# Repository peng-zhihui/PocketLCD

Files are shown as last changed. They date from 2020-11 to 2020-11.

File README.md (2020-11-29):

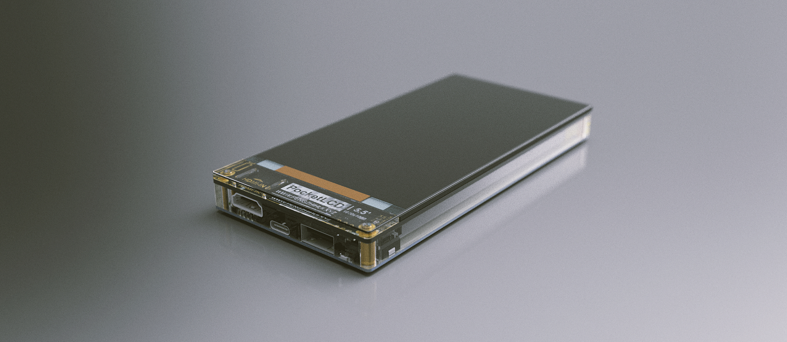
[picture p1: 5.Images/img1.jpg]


# PocketLCD: 带充电宝功能的便携显示器

项目的视频介绍可以在这里看： [【自制】你的下一个显示器，可能是个充电宝？？](https://www.bilibili.com/video/BV17D4y1X7AT)

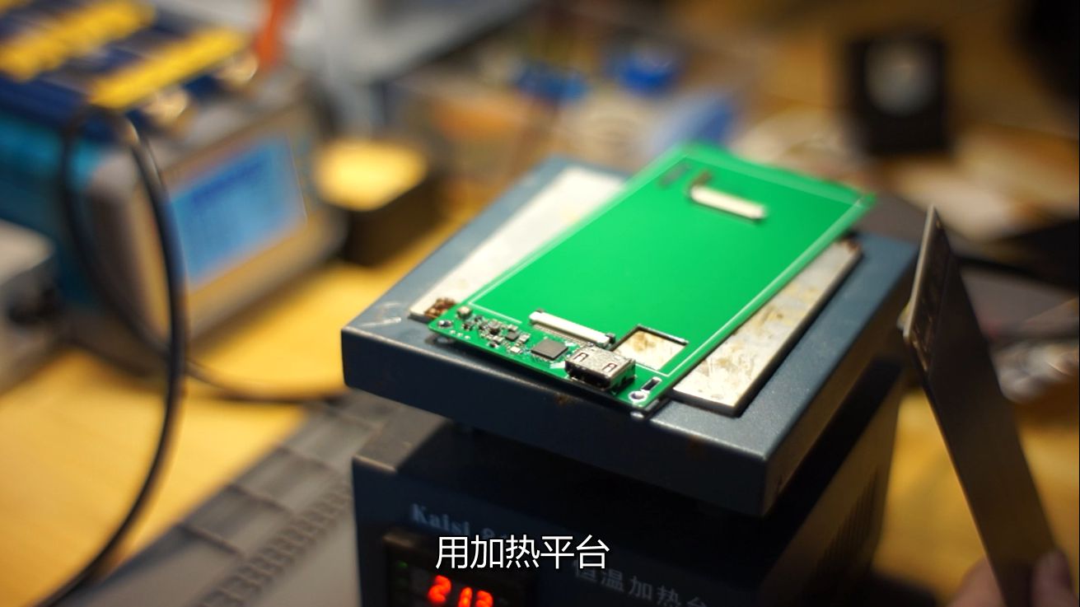
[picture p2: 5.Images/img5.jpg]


总的来说，这是我最近为了解决个人痛点设计制作的一个便携口袋显示器，最终成品的完成度比较高所以也就顺便开源分享出来了。

> 其中屏幕显示部分是基于我之前开源另一个项目`HDMI-PI`，关联仓库地址在这里：
>
> https://github.com/peng-zhihui/HDMI-PI

## 关于屏幕选型

如视频介绍中所述，MIPI并不是一个通用的接口，需要针对不同的屏幕模组定制驱动固件，这一块比较复杂所以建议大家直接用我编译好的固件进行烧录。

屏幕的型号是5.5英寸的1080P IPS屏幕，我是在这里购买的（非广告）[5.5寸TFT屏 IPS 1080*1920 亮度300 MIPI ](https://item.taobao.com/item.htm?spm=a1z09.2.0.0.7f172e8dEWrdmp&id=543793236047)

价格不贵就100元，显示效果还是很理想的。

## 电路的一些说明

1. 充电宝快充的时候电流会比较大，所以PCB上是有开窗处理的，在焊接的时候记得把开窗的地方多上点焊锡增加导线厚度。
2. HDMI转MIPI板子的设计使用了0.5mm的FPC连接线，实际上是可以用PCB走线代替的，我这里这样设计的原因是想留出接口，便于以后扩展调试其它型号的屏幕。当然如果你没有这个需求的话，可以把电路改一下这样焊接和物料都会更省事，不过MIPI的走线要注意符合信号完整性规则（等长、阻抗）。
3. LED的阻值可以自己调整，目前原理图里面的阻值会稍微有点亮；屏幕的背光的亮度由那个10R的电位器调节。
4. 充电宝有一个功能按键，按一下查看电量，按两下强制关闭输出；如果PD协议开启了，最左边会有一个指示灯亮起，普通5V充电则不亮。
5. 购买充电宝电芯注意买不需要保护模块的，因为板子已经集成了一个保护模块，或者你不焊那个保护模块，然后搭配带保护的电芯使用。
6. 铜柱和PCB之间通过焊锡固定，这个要考虑好组装顺序，不然拆起来会比较麻烦。

**最后，喜欢的话记得给仓库点星星~**

> 另外强调一下，本仓库的项目是**GPL协议**，不支持任何形式的私自产品化（当然大家自己DIY是没有任何问题的，这里只是防止有人借我的名义坑大家），我个人工作比较忙所以也没有建任何官方的QQ、微信群等，大家自己加群的时候要注意甄别。

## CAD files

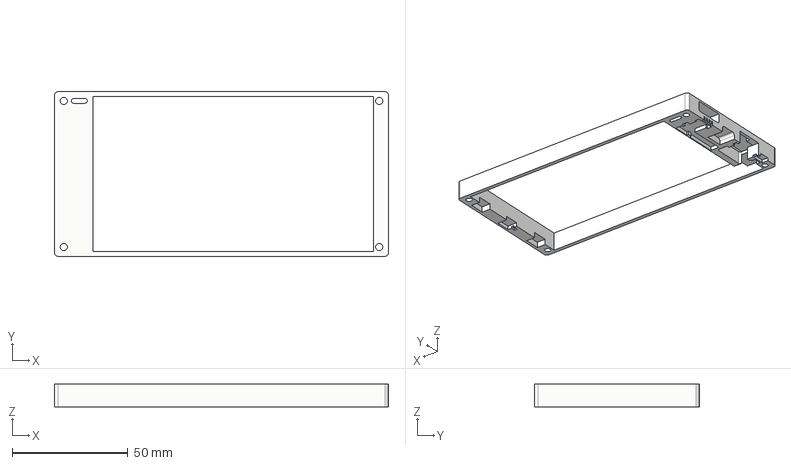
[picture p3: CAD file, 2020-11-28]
3.Model/亚克力中框.step
144.0 x 71.0 x 9.80 mm

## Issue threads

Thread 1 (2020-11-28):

屏幕型号是什么...

ActivePeter, 2020-11-28:

csr865, 2020-11-29:
> _没有提供描述。_

啊这，那怎么办啊😯

WillzenZou, 2020-11-29:
查了下之前稚晖君之前那个项目，对比了下现在的项目，应该是这个屏幕了：
5.5inch 1080X1920 IPS MIPI AML550L3901 Shenzhen Amelin Electronic Technology Co. Ltd

https://github.com/peng-zhihui/HDMI-PI/tree/main/4.Docs/%E5%B1%8F%E5%B9%95%E8%B5%84%E6%96%99/5.5inch%201080X1920%20IPS%20MIPI%20AML550L3901%20Shenzhen%20Amelin%20Ele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

WillzenZou, 2020-11-29:
查了下之前稚晖君之前那个项目，对比了下现在的项目，应该是这个屏幕了：
5.5inch 1080X1920 IPS MIPI AML550L3901 Shenzhen Amelin Electronic Technology Co. Ltd

https://github.com/peng-zhihui/HDMI-PI/tree/main/4.Docs/%E5%B1%8F%E5%B9%95%E8%B5%84%E6%96%99/5.5inch%201080X1920%20IPS%20MIPI%20AML550L3901%20Shenzhen%20Amelin%20Ele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

fzwwj95, 2020-11-29:
屏幕型号不确定+只有HEX文件 = 得自己写套驱动吧

ActivePeter, 2020-11-29:
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

他也不说一下是哪个手机的屏幕呐==

peng-zhihui, 2020-11-29:
已经更新了，看README

bushiniu, 2020-12-13:
物料单有个就好了

Closed 2020-11-29.

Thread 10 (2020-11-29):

大家一起拼pocket-lcd qq群719019471，正在踩坑，年前应该可以发货。满100人就发车

Professor-Chen, 2020-11-29:

hot36952, 2020-11-29:
搜索不到群号

Professor-Chen, 2020-11-29:
现在可以了

tank1293955, 2020-11-30:
已提交入群申请。

zhanghang1989, 2020-12-02:
可以搞个微型群吗，qq现在不让登陆了

pengzi007, 2020-12-03:
我已经在某宝店铺：**极客出版社** 下单了，你们是一起的吗？

zhanghang1989, 2020-12-03:
> 我已经在某宝店铺：**极客出版社** 下单了，你们是一起的吗？

👍 这个好，我没办法加群，直接下单了

zhoucray, 2020-12-05:
我也在这家下单了

---原始邮件---
发件人: "Hang Zhang"<notifications@github.com&gt;
发送时间: 2020年12月4日(周五) 凌晨1:57
收件人: "peng-zhihui/PocketLCD"<PocketLCD@noreply.github.com&gt;;
抄送: "Subscribed"<subscribed@noreply.github.com&gt;;
主题: Re: [peng-zhihui/PocketLCD] 大家一起拼pocket-lcd qq群719019471，正在踩坑，年前应该可以发货。满100人就发车 (#10)

我已经在某宝店铺：极客出版社 下单了，你们是一起的吗？

👍 这个好，我没办法加群，直接下单了

—
You are receiving this because you are subscribed to this thread.
Reply to this email directly, view it on GitHub, or unsubscribe.

Closed 2020-12-03.

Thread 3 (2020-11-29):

屏幕

csr865, 2020-11-29:
屏幕哪里买？型号或链接🔗，谢谢啦

ZinlinCc, 2020-11-29:
某宝搜5.5 lcd mipi 出来的就差不多了

WillzenZou, 2020-11-29:
查了下之前稚晖君之前那个项目，对比了下现在的项目，应该是这个屏幕了：
5.5inch 1080X1920 IPS MIPI AML550L3901 Shenzhen Amelin Electronic Technology Co. Ltd

https://github.com/peng-zhihui/HDMI-PI/tree/main/4.Docs/%E5%B1%8F%E5%B9%95%E8%B5%84%E6%96%99/5.5inch%201080X1920%20IPS%20MIPI%20AML550L3901%20Shenzhen%20Amelin%20Ele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

nineandthreequarters, 2020-11-29:
# 关于屏幕、DSI和树莓派
   >树莓派有 **_DSI_** +手机屏幕用 **_DSI_**  ==> 树莓派可以直接连手机拆机屏幕进行显示
- [ ] **这条假设成立吗？**

WillzenZou, 2020-11-29:
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

理论上可行，要先看硬件和带宽能不能满足(几line)，然后相关驱动和信号线得转接之类的[吃瓜]不过我也不太熟MIPI

datidu, 2020-11-29:
淘宝上有贵的有便宜的 QAQ 难受了一个一个问吧

ActivePeter, 2020-11-29:
> 某宝搜5.5 lcd mipi 出来的就差不多了

不同的屏幕初始化指令都不一样。很难通用的

peng-zhihui, 2020-11-29:
看README，已更新

Closed 2020-11-29.

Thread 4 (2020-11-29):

关于亚克力中框的疑惑

Hemistic, 2020-11-29:
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

为什么这里的hdmi接口是封闭的，还是我打开的方式不对？

fzwwj95, 2020-11-29:
是封闭的，通过分层+双面雕刻，最后叠在一起实现的

fzwwj95, 2020-11-29:
三层的叠加效果
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

Hemistic, 2020-11-29:
> 三层的叠加效果
> 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

懂了，谢谢

tth1996, 2020-11-29:
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
我觉得稚辉君打的板子不是1.6mm的 图片上看起来略薄 而且他在最上面一层加了一张PCB小板以弥补屏幕的厚度方便贴膜

peng-zhihui, 2020-11-29:
板子厚度再PCB堆栈设置里可以看到的，都是1mm，然后上面是加了一小块1.6mm的PCB正好和屏幕等高。中框的加工是切成两块，其中一块2D切割，另一块如视频里所述是正反两面雕刻的，最后组装到一起。

Hemistic, 2020-11-29:
> 板子厚度再PCB堆栈设置里可以看到的，都是1mm，然后上面是加了一小块1.6mm的PCB正好和屏幕等高。中框的加工是切成两块，其中一块2D切割，另一块如视频里所述是正反两面雕刻的，最后组装到一起。

可以问一下板上的栅格开口是不是给喇叭box的？如果是，那是什么型号呢？

Closed 2020-11-29.

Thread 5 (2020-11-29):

屏幕型号、BOM表

ClimbSnail, 2020-11-29:
不知道具体是哪个屏幕，应该不是通用的吧？如果生成一个BOM表就更好了

WillzenZou, 2020-11-29:
屏幕稚晖君之前另一个项目有，还有一个10.1寸屏的固件
查了下之前稚晖君之前那个项目，对比了下现在的项目，应该是这个屏幕了：
5.5inch 1080X1920 IPS MIPI AML550L3901 Shenzhen Amelin Electronic Technology Co. Ltd

https://github.com/peng-zhihui/HDMI-PI/tree/main/4.Docs/%E5%B1%8F%E5%B9%95%E8%B5%84%E6%96%99/5.5inch%201080X1920%20IPS%20MIPI%20AML550L3901%20Shenzhen%20Amelin%20Ele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

tansirui, 2020-11-29:
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

你好，请问你找到谁家卖这款屏幕吗？可以找到这个屏幕的厂家官网，但是没有购买链接。

WillzenZou, 2020-11-29:
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

找到了，还有TYPE-C驱动板全套的，300左右
另外淘宝上或者阿里巴巴搜FRD550L3901能找到80左右的单屏幕，但是邮费贵

Liunkwww, 2020-11-29:
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

官方淘宝店有，但邮费略贵
https://item.taobao.com/item.htm?spm=a1z10.3-c.w4002-18603147148.13.1e9e4b9fGSY1En&id=543793236047

peng-zhihui, 2020-11-29:
看README，已更新

Closed 2020-11-29.

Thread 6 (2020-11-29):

可调电阻R6的范围是多大啊?

ZinlinCc, 2020-11-29:
这个电阻接反馈应该是限流用的。但是这个范围你们觉得应该买多大。是不是差不多几K就够用了？

WillzenZou, 2020-11-29:
> 这个电阻接反馈应该是限流用的。但是这个范围你们觉得应该买多大。是不是差不多几K就够用了？

应该够了，这个是调亮度的，阻值越小，亮度越大来着，我看手册看到的。
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

tth1996, 2020-11-29:
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
推荐的阻值是15欧

peng-zhihui, 2020-11-29:
10R够用

Closed 2020-11-29.

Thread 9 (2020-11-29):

建议Hardware另存为ASCII格式的文件

yuduzhu, 2020-11-29:
在立创EDA软件中打不开，麻烦修改一下谢谢！对某些的软件支持更加的友好！尤其是在MAC系统上！谢谢！
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

Jyishit, 2020-11-30:
我转换好了，已经上传百度网盘了
链接：https://pan.baidu.com/s/1x1g0m_GrqecdZyFr51FWyA
提取码：6666
在AD里另存出来的，导入到立创EDA里看着大概没问题，但是还没有细看
我之前的一个板子导入之后导线错位了，所以使用的话请谨慎点

wangbokun, 2022-06-06:
>

这个错误修复了吗？

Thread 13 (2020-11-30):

请问LT6911芯片的固件是需要提前烧录吗？

411956158, 2020-11-30:
尊敬的作者您好，
感谢您分享如此精妙实用的硬件设计，我在diy备料过程中发现LT6911需要烧录固件，请问需要提前烧录好再焊接，还是焊接后通过板载接口烧录程序呢？
希望有幸得到您的回复，不胜感激

Mar1n3, 2020-11-30:
HDMI_To_MIPI已经预留了IIC烧录接口
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
所以可以焊接好再烧录
参见[烧录说明](https://github.com/peng-zhihui/HDMI-PI/tree/main/4.Docs/%E9%BE%99%E8%AE%AF%E6%96%B9%E6%A1%88)

oumaiguo, 2021-01-25:
我烧录一直失败 头大

he831216, 2023-10-31:
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
这个版本的HDMI转MIPI是不是没准备烧录口啊。
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
还是通过啥烧录。

Lesterbor, 2023-11-10:
显示I2C一直离线快自闭了~

Closed 2020-11-30.

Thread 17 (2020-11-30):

想知道大佬怎么把AD的pcb文件导入到fusion360的

jieren30, 2020-11-30:
想知道大佬怎么把AD的pcb文件导入到fusion360的

ZinlinCc, 2020-12-01:
先用ad导出step文件。再用fusion360打开。你可以百度一下ad导出3d模型到solidworks，有教程的

NPcc-c, 2021-11-24:
我试过了导入一直达不到想要的效果，我严重怀疑他是直接在fusion360上面画的板子

AERCR3, 2024-06-27:
ad导出ascll格式文件直接在fusion360新建个原理图，然后自动化运行选择运行ulp，找到导入ascll文件就能导入sch和pcb，但是目前我还不知道怎么导入pcblibrary库，同样方法schlibrary也能导入，似乎需要将pcblibrary全部铺到一样pcb文件中导入就能导入fusion360了

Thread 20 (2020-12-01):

烦请稚晖君推荐个10.1-15.6寸的屏幕

fzwwj95, 2020-12-01:
想做个便携的的屏幕
作为副屏绘制PCB时候使用，因为也有一些视频编辑、图片PS等需求，笔记本自带屏幕不怎么好。兼顾便携性所以想做个便携的屏幕。
烦请稚晖君安利个10.1-15.6寸的屏幕（100%sRGB、1080p及以上，最好支持DC调光），不知道稚晖君有没这方面的推荐

NirViaje, 2021-01-26:
> 想做个便携的的屏幕
> 作为副屏绘制PCB时候使用，因为也有一些视频编辑、图片PS等需求，笔记本自带屏幕不怎么好。兼顾便携性所以想做个便携的屏幕。
> 烦请稚晖君安利个10.1-15.6寸的屏幕（100%sRGB、1080p及以上，最好支持DC调光），不知道稚晖君有没这方面的推荐

edp的屏随便挑一块，以前9.7寸有ipad的屏挺好用

dandanheng, 2021-07-13:
淘宝搜gobigger

> 想做个便携的的屏幕
> 作为副屏绘制PCB时候使用，因为也有一些视频编辑、图片PS等需求，笔记本自带屏幕不怎么好。兼顾便携性所以想做个便携的屏幕。
> 烦请稚晖君安利个10.1-15.6寸的屏幕（100%sRGB、1080p及以上，最好支持DC调光），不知道稚晖君有没这方面的推荐

Closed 2022-10-30.

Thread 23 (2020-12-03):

可不可以上传一下亚克力上下盖的模型

MengxingFusheng, 2020-12-03:

fzwwj95, 2020-12-04:
有开源出来呀

MengxingFusheng, 2020-12-04:
> 有开源出来呀
不是只有中框吗

fzwwj95, 2020-12-04:
上面是屏幕和信号转换板，底下是充电宝的板子呀，中间夹着中框

ufo250120, 2020-12-05:
你们用啥软件打开的亚克力中框.step文件，我的soliderworks打开时说有错误？

ZinlinCc, 2020-12-11:
> 你们用啥软件打开的亚克力中框.step文件，我的soliderworks打开时说有错误？
sw开step文件一直都会报错的吧好像，他那个更像不是他的格式所以发了个警告的感觉。上网查一下，没啥问题的。

ufo250120, 2020-12-11:
可以打开，你把那些文件整体下载，不要单独下载亚克力外框，或加我QQ好友我发你一下1661623548 ------------------&nbsp;原始邮件&nbsp;------------------
发件人:&nbsp;&quot;ZinlinCc&quot;<notifications@github.com&gt;
发送时间:&nbsp;2020年12月11日(星期五) 上午10:05
收件人:&nbsp;&quot;peng-zhihui/PocketLCD&quot;<PocketLCD@noreply.github.com&gt;;
抄送:&nbsp;&quot;ufo250120&quot;<1661623548@qq.com&gt;;&quot;Comment&quot;<comment@noreply.github.com&gt;;
主题:&nbsp;Re: [peng-zhihui/PocketLCD] 可不可以上传一下亚克力上下盖的模型 (#23)

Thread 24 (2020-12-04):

个人制作成本高昂，为方便大家制作，降低大家成本，让每个热爱DIY的人不再为材料发愁，现在我们已开启散件拼团，有元器件包，有PCB板

Professor-Chen, 2020-12-04:
拼团链接：https://item.taobao.com/item.htm?spm=a2oq0.12575281.0.0.20311debtZZWIr&ft=t&id=632909593810
拼团群号：719019471

Professor-Chen, 2020-12-04:
> 拼团链接：https://item.taobao.com/item.htm?spm=a2oq0.12575281.0.0.20311debtZZWIr&ft=t&id=632909593810
> 拼团群号：916619857

Closed 2020-12-04.

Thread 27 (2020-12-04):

好奇为什么不采用东芝的TC358870XBG方案

fzwwj95, 2020-12-04:
TC358870XBG方案功能更强大，资料也相对较多，好奇为什么不采用东芝的TC358870XBG方案而选择了龙讯方案呢

xiushudongfang, 2020-12-05:
请移步 HDMI-PI 项目  哪里有说明

fzwwj95, 2020-12-05:
> 请移步 HDMI-PI 项目 那里有说明

请问HDMI-PI 项目哪里有说明呢？您觉得说明的理由是什么呢？难道是"这个方案的软件我还没有写"吗

doublemarkpro, 2020-12-07:
个人喜好，up用Plan A做出来并开源已经够可以的了，为什么还有『我觉得plan B更好』『为什么不用plan B』质疑呢……

Matthewow, 2020-12-07:
> > 请移步 HDMI-PI 项目 那里有说明
>
> 请问HDMI-PI 项目哪里有说明呢？您觉得说明的理由是什么呢？难道是"这个方案的软件我还没有写"吗

"成本相对较低，芯片外围电路也更简洁"

Closed 2020-12-08.

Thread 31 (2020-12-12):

求助 做好之后 出现问题

gyy0814, 2020-12-12:
做好之后 插在我的笔记本电脑上 会出现红点 然后我又插在台式机上测试 红点消失 但是开始闪屏 插树莓派3B测试 半个屏幕是白的  然后中间有一小条显示
后来把底板拆下 只留HDMI_MIPI的那块 用可调电源供电 插在台式机上 问题消失 正常显示 但是笔记本和树莓派故障依旧
目前没查到啥问题
求助大佬们
QQ 2691325401

gyy0814, 2020-12-16:
求帮助 ing

colinkyd, 2020-12-17:
我用树莓派3B跟你一样 不过笔记本和台式机都正常  用另一个派直接开机也不显示

gyy0814, 2020-12-17:
那您是用的power_bank供电的吗 我用power_bank板供电的话在我的台式机会出现闪屏现象 而用可调电源的话 这个问题将消失 方便的话可以加一下qq交流下吗
*⸜( •ᴗ• )⸝*

colinkyd, 2020-12-17:
那你底板有问题呗

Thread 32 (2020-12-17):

树莓派3B直接先插HDMI再开机会花屏 用另外一个"派"开机不显示,要HDMI查一下正常显示器再插回PocketLCD才能显示

colinkyd, 2020-12-17:

gyy0814, 2020-12-17:
您好  我的问题是会显示一半  我感觉是因为屏幕默认上竖着显示的问题 并且也测试了切换显示方向 都是只有一半

gyy0814, 2020-12-17:
方便的话可以加一下QQ交流下吗
ฅ۶•ﻌ•♡

colinkyd, 2020-12-17:
> 您好 我的问题是会显示一半 我感觉是因为屏幕默认上竖着显示的问题 并且也测试了切换显示方向 都是只有一半

我和你问题一样

fzwwj95, 2020-12-18:
和驱动有关？

poisonousfish, 2021-01-06:
看看config.txt是否指定了对应分辨率

colinkyd, 2021-01-15:
> 看看config.txt是否指定了对应分辨率
 插电脑显示器正常显示

corrugatorsupercilii, 2022-08-24:
Tested on Pi Zero W 2, the EDID from PockeLCD

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

_Edits for /boot/config.txt_

#5.5 inch 1080x1920@60Hz
#Display in landscape mode...
config_hdmi_boost=10
hdmi_group=2
hdmi_mode=87
max_framebuffer_width=1080
max_framebuffer_height=1920
#From EDID.dat 60Hz, unfortunately didn't work
#hdmi_timings = 1080 0 72 8 16 1920 0 14 4 4 0 0 0 60 0 137000000 3
#Using HDMI timing calculator @59.94Hz
hdmi_timings= 1080 0 72 8 16 1920 0 14 4 4 0 0 0 60 0 136890490 3
display_hdmi_rotate=3

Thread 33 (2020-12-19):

为大家提供一个全包裹亚克力外壳, 试验了5种加工方案, 以最低成本量产, 最终成型, 欢迎大家来上车

geeke2008, 2020-12-19:
拼团链接:  https://item.taobao.com/item.htm?spm=a230r.1.14.16.45ec2850JbE4Gv&id=633212660989
拼团群:  811617528

亚克力材料能有效的解决3D打印外壳的强度偏软易变形的问题, 全包裹设计更能提高便携性, 让PockerLCD不再是办公桌上的玩具, 不再担心屏幕磕碰, 电路板划伤问题, 让你能随身携带!

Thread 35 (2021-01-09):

请问一下各位大佬

skq7929, 2021-01-09:
在淘宝上买的CH341T，参照HDMI-MIPI里面的烧录文档烧录固件，一直显示是失败，能确定LT6911C是焊好的，对地值、对应的电压都正确，外部用充电器直接供的5V的电，HDMI线有插上，烧录固件就是一直失败，请问下有没有遇到一样问题的朋友？请问下大佬这大概是哪方面的问题？

ZhaoXiangBox, 2022-02-28:
我也遇见同样的问题了，有大佬说是IIC 没有上拉电阻，不知道具体是啥原因

Closed 2021-01-11.

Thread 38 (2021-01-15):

关于高亮屏 LED背光电路是否支持42V屏幕

CmST0us, 2021-01-15:
自己在定制PocketLCD的屏幕, 用的一块800nit的高亮屏
屏幕LED 电压为 42V 电流 40mA

我查了一下rt9293bj6 的 VOP 为50V, 在 Vref = 300mV 的情况下 Rset = 300mV / 40mA = 7.5欧
我调整电阻Rset到7.5左右之后 发现 LED + ~ LED - 之间的电压只能到 35.6 V

请教一下可能是什么原因

CmST0us, 2021-01-19:
已找到驱动ic, 成功驱动背光
使用方案 bp1808

guanzi008, 2021-04-03:
...

Closed 2021-01-19.

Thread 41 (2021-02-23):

新人试水卡裆了···

hzc1111, 2021-02-23:
我正在做这个神器，电路已经焊好了，电路目测没有明显的问题，但是还是遇到两个问题卡住了：
1.充电宝部分type-C口能充电，USB口能输出5V，但是导电铜柱输出只有2.3V，这是正常的吗？因为没有成功案例参考，不确定哪些现象正常哪些不正常；
2.屏幕部分烧录驱动失败，也不知道是什么问题，如果说这跟问题1有关，那我用其他方式另外给它供电也还是失败的，除了烧录文档上写有的，是还有什么注意事项我遗漏的吗？
当然由于设备和技术等因素，很大的可能性是电路焊接导致的，但是一方面物料没那么充足（已经废了三四套物料了），经不起我随便造，一方面没有成功案例参照（稚晖君本尊的“不算复杂”就不提了），望各位大佬们指教

hzc1111, 2021-02-24:
更新一下问题，前面提出的这两个问题其实不算故障，第一个，两个导电铜柱之所以没测到正常输出电压，是因为快充芯片没检测到有效负载，然后刚好第2个问题刚好阻碍了我对问题1的判断，我经过检测发现屏幕驱动芯片并没有供上电，这也是烧录失败的原因，仔细研究原理图后，是因为供电入口处的MOS管没导通，原来稚晖君用了一个三极管作为使能开关，当检测到HDMI供电时三极管导通，然后MOS管才导通，这时候整个电路才算通上电，芯片才能正常工作。也就是说，当你焊接好电路后，必须要接上充电宝部分，再插上具有有效信号的HDMI线，再接上烧录模块，这时才能够成功烧录驱动程序。
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
尽管解决了之前的问题但是仍未能让屏幕亮起来，通电时，屏幕芯片有点微微发热，但没有持续升温，测了一下屏幕背光VLED的电压，有45V，我不确定这正不正常，猜测应该用不了这么高的电压，又看了下RT9293升压芯片的数据手册，好像没毛病，倒是那个EA3036电源IC烧了几片了，不知道什么原因

gyy0814, 2021-02-27:
看一下是不是短路了吧
测测各个电压的对地阻值
（我也是新手）

kakalinlin, 2021-02-28:
测一下mipi线吧，我之前也是不亮

Tangcu-yu, 2024-01-15:
请问复刻成功了吗，我现在没连屏幕但是按理说充电宝功能应该是可以独立使用的

oumaiguo, 2024-05-01:
别自己弄了，他那设计的 ic 都是老版本的，现在买的原理图脚位都不一样。直接去买二手成品还便宜

ding-f, 2025-01-18:
ic nt35532的屏幕已经停产，各大平台已经没有任何渠道可以买到了，除非某鱼。。

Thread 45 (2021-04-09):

刷了固件，但没有显示，背光和电源都正常，屏是链接购买的型号

jeff-ning, 2021-04-09:
所用的屏是5.5寸TFT屏 IPS 1080*1920  型号 AML055-FHD-056A，固件是网上显示的，固件烧录成功，有背光，但没有显示。网上提个的固件代码是对应这个 AML055-FHD-056A型号吗？

jeff-ning, 2021-04-09:
大神，
屏的驱动IC是NT35532吗？之前从链接上买的型号驱动IC是ILI7807D，这个点不亮。

quannhe18, 2023-01-17:
same with you, the screen go from black to White slowly and check IC: ILI7807D. what can i do now for fix this situation

Tangcu-yu, 2024-01-15:
请问你充电宝功能是正常的吗

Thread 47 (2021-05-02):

求此屏幕在jetson nano上的设置方法

liumarcus70s, 2021-05-02:
已通过修改config.txt的方法让此屏幕正常工作在pi3B上，手里还有一个初代jetson nano，求屏幕解决方案。
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
这是pi3b配置config.txt以前的样子
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
这是配好后
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
这是jetson nano
=================================================================
求高手

daniel199904, 2021-06-09:
$ xrandr -o left 向左旋轉90度
$ xrandr -o right 向右旋轉90度
$ xrandr -o inverted 上下翻轉
$ xrandr -o normal 回到正常角度

不確定是否有效

liumarcus70s, 2021-06-09:
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

试过了，无效。据说原因是因为我那个是初代nano，显示芯片比较原始，次代好像就可以了

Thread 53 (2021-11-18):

powerbank电池焊上后，VBUS_A1和VBUS_A2应该是5V吗？

LimboFly, 2021-11-18:
我测出来在2.3V左右，是不是有点问题。。。。

LimboFly, 2021-11-18:
电池是3.7V锂电池

LimboFly, 2021-11-19:
没事了，按下按钮VOUT5伏了,LED灯也亮了，充放电正常

Closed 2021-11-19.
